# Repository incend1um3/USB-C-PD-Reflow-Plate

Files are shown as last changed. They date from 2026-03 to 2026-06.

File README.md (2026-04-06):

<h1 align="center">
	USB-C PD Reflow Plate
	<br />
	<br />
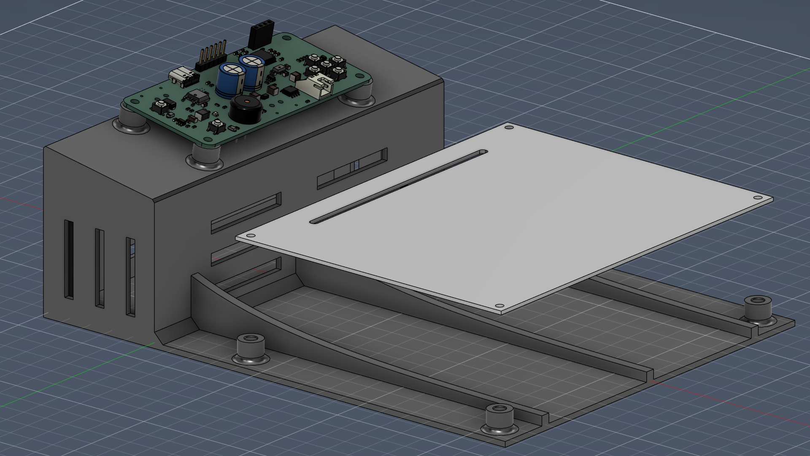
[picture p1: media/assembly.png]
Assembly
	
	<br />
</h1>

<h4 align="center">
A DIY PCB Reflow Plate. Accepts 300W from a DC power source, or 110W from USB PD.
</h4>

<div align="center">





</div>

<p align="center">
  <a href="#key-features">Key Features</a> •
  <a href="#hardware">Hardware</a> •
  <a href="#building-and-flashing-the-firmware">Building and Flashing</a> •
  <a href="#license">License</a>
</p>

## Key Features

- **Split design** that allows you to manufacture the heater PCB using aluminum
- Accepts **USB-C PD (up to 110W)** or **DC supply (up to 300W)**
- **STM32G431KBT6 microcontroller** with support for flashing over USB and SWD
- **1.3" OLED display** for selecting alloys and showing progress
- **40 KHz PWM power delivery** to the heating element + a **970μF capacitor bank** to keep the average current under power supply limits

## Motivation

I started this project because existing designs had some flaws I disliked such as:

- No USB-C PD support
- Using obsolete Atmega chips that are too expensive for what they offer
- Not being powerful enough or requiring AC voltages which I don't want to mess around with
- Putting the electronics and heating elements on the same FR-4 PCB, making the longevity of the board questionable

This project is intended to address all these issues.

## Hardware

The hardware is split into two separate PCBs - a controller board and the heating element. This allows you to manufacture the heating element using aluminium to increase its longevity.

### Controller Board

#### Schematic

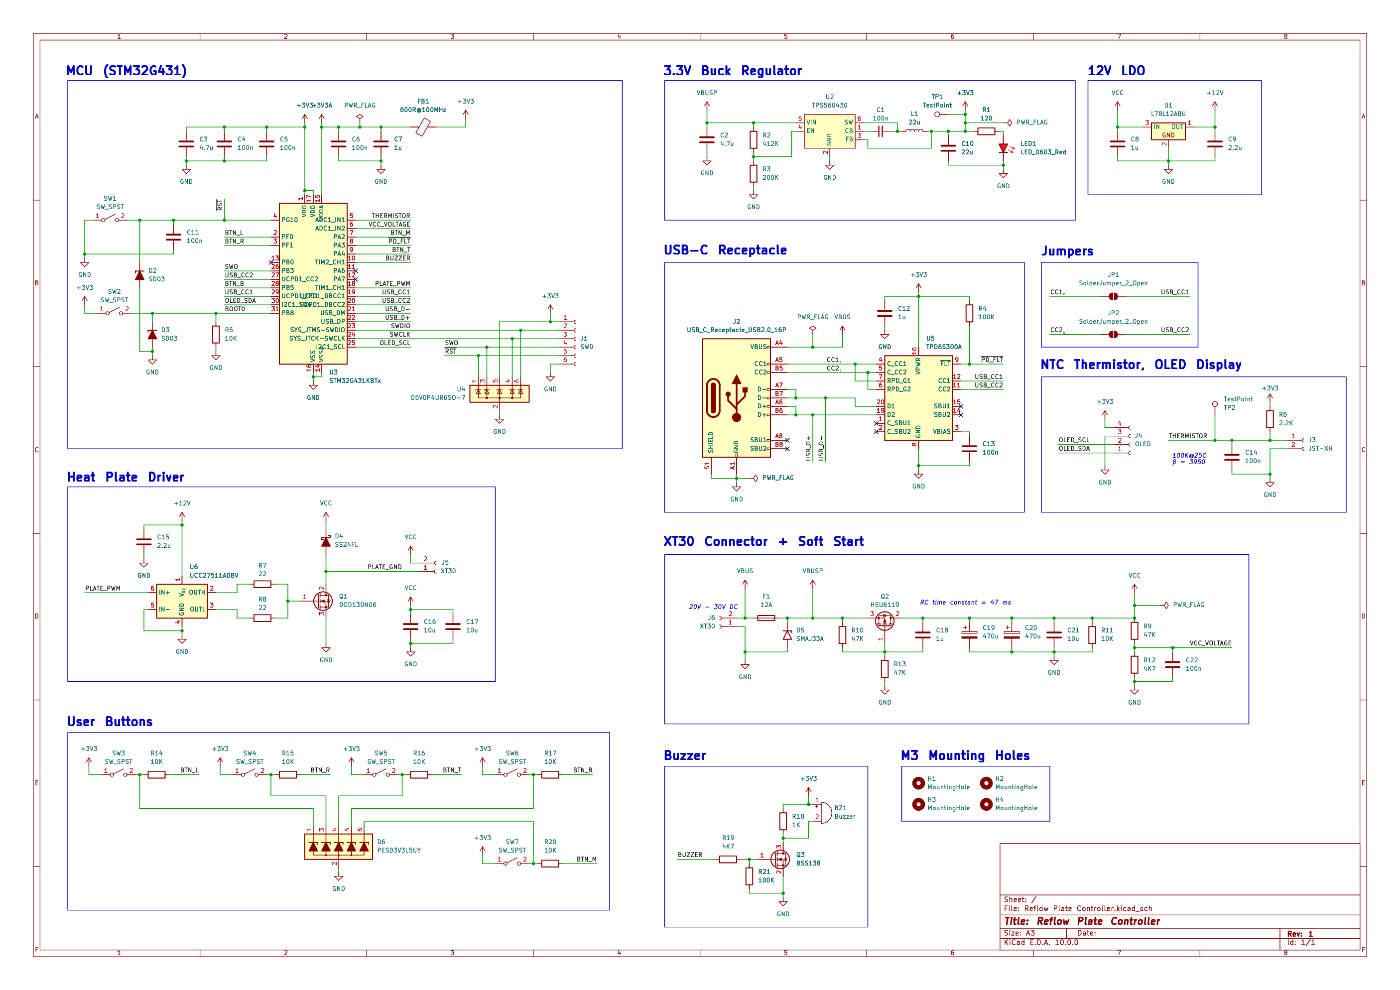
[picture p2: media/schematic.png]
Schematic


#### PCB

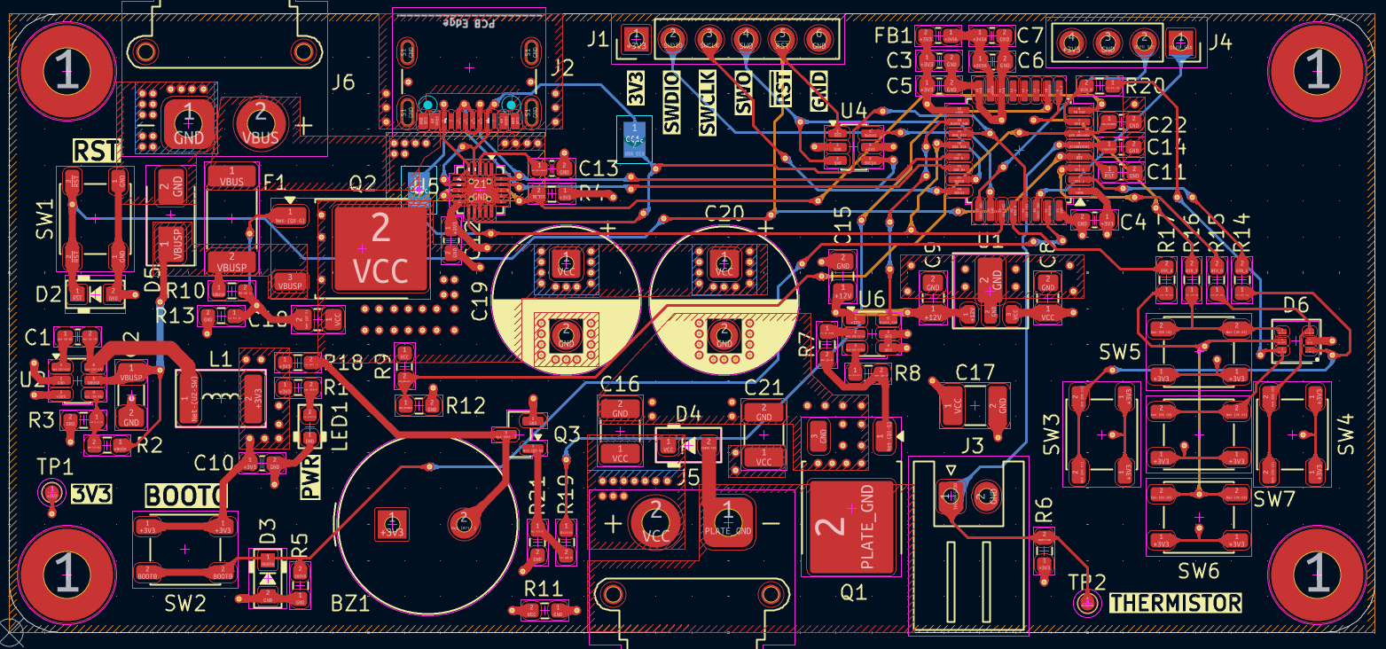
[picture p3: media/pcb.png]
PCB


The controller PCB uses a 4 layer SIGNAL-GND-PWR-SIGNAL stackup. It measures under 100x50 mm, so you can get it manufactured for cheap at JLCPCB. 2x 470μF aluminum polymer capacitors are used to keep the average current within limits and smooth out the power supply.

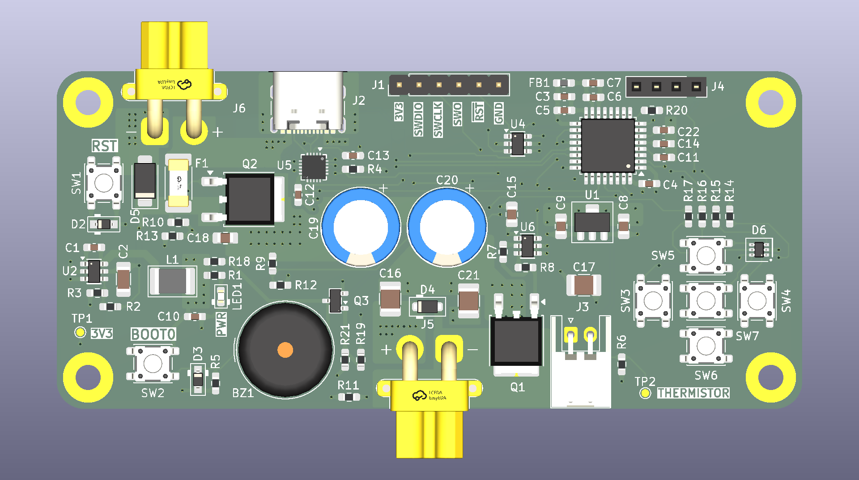
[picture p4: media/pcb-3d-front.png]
PCB 3D Render


### Heating Element

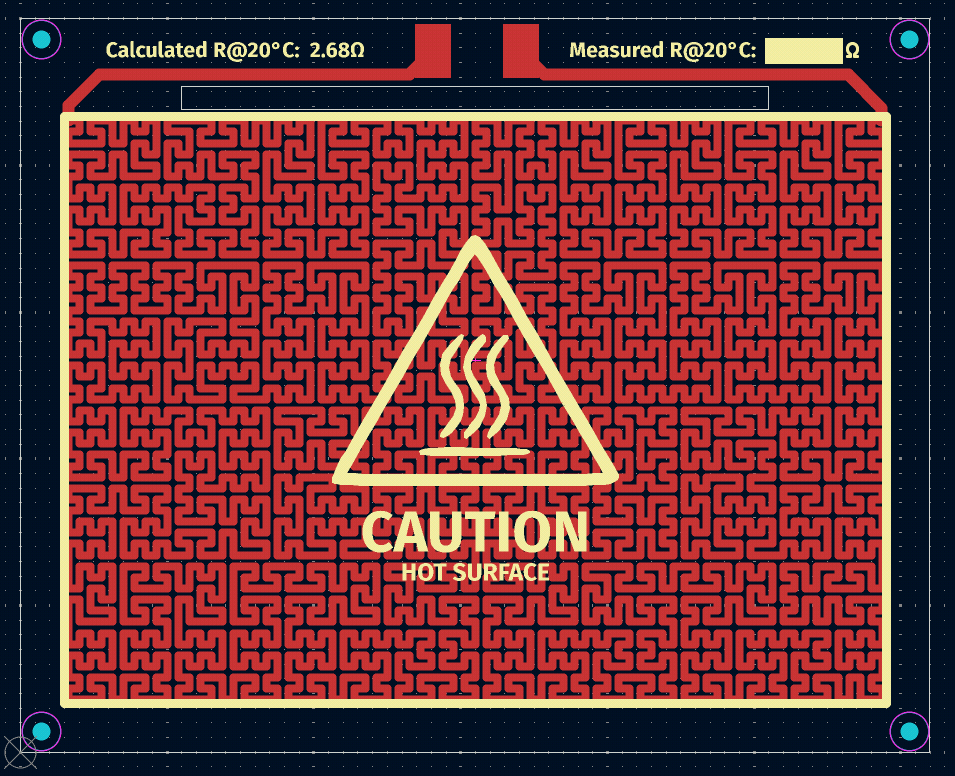
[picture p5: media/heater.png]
Heating Element


The traces are generated using the [Heater Generator Plugin](https://github.com/steltze/KiCad-Heater-Generator-Plugin), which uses the Hilbert Space Filling Curve to generate traces in a given bounding box.

The calculated resistance at 20°C is approximately 2.68Ω. The actual resistance after manufacturing can vary, but slight differences should not be a problem as long as the firmware is updated with the new value.

## Chassis

The chassis is made in Fusion360 and is designed to be printed using SLS/MJF nylon at JLC3DP. It occupies a bounding box of 220x166x73 mm and a total volume of 179 cm³.

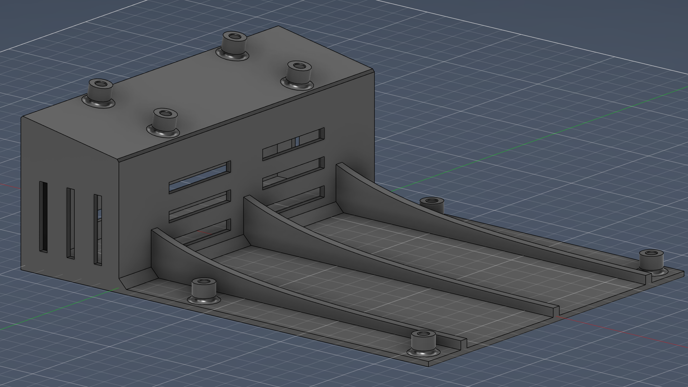
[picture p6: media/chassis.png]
Chassis


## Manufacturing

All files related to manufacturing can be found in the `production` folder.

### BOM

<details>
<summary>Click to Expand / Collapse</summary>
<br />

The list of PCB components can be found [here.](production/Reflow%20Plate%20Controller/BOM-Reflow%20Plate%20Controller.csv)

| Name | Comment | Price ($USD) | Link |
|---|---|---|---|
| PCB Components | | $25.63 | production/Reflow Plate Controller/BOM-Reflow Plate Controller.csv |
| 1.3" SSD1315 OLED Display | | $2.43 | <https://www.aliexpress.com/item/1005008365029314.html> |
| Glass NTC Thermistor | Must be able to withstand at least 250C | $4.03 | <https://www.aliexpress.com/item/1005008996648273.html> |
| Kapton Tape | For attaching the thermistor to the heating element | $2.72 | <https://www.aliexpress.com/item/33036160119.html> |
| XT30 Female Connector | For connecting the controller to the heating element | $2.17 | <https://www.aliexpress.com/item/1005011848365155.html> |
| M3x12 PEEK Screws | PEEK material chosen for insulation | $4.90 | <https://www.aliexpress.com/item/1005009212510720.html> |
| M3 Ceramic Washers | For insulation | $10.07 | <https://www.aliexpress.com/item/1005006898159426.html> |
| M3x45 Stainless Steel Standoffs | For insulation and attaching the heating element to the chassis | $2.55 | <https://www.aliexpress.com/item/1005010143571846.html> |
| M3x8 Screws | For attaching the controller PCB to the chassis | $1.61 | <https://www.aliexpress.com/item/1005010666684312.html> |
| M3x5x5 Heat Set Inserts | | $1.28 | <https://www.aliexpress.com/item/1005010449185019.html> |
| JLCPCB (Controller Board) | | $7.00 | |
| JLCPCBA (Controller Board) | | $14.53 | |
| JLCPCB (Heating Element) | | $12.40 | |
| JLC3DP (SLS 1172Pro Nylon) | | $59.95 | |
| JLCPCB Shipping | | $16.17 | |
| JLC3DP Shipping | | $17.07 | |
| LCSC Shipping | | $14.80 | |
| **Total** | | **$200.00** | |

</details>

### JLC Cart

<details>
<summary>Click to Expand / Collapse</summary>
<br />

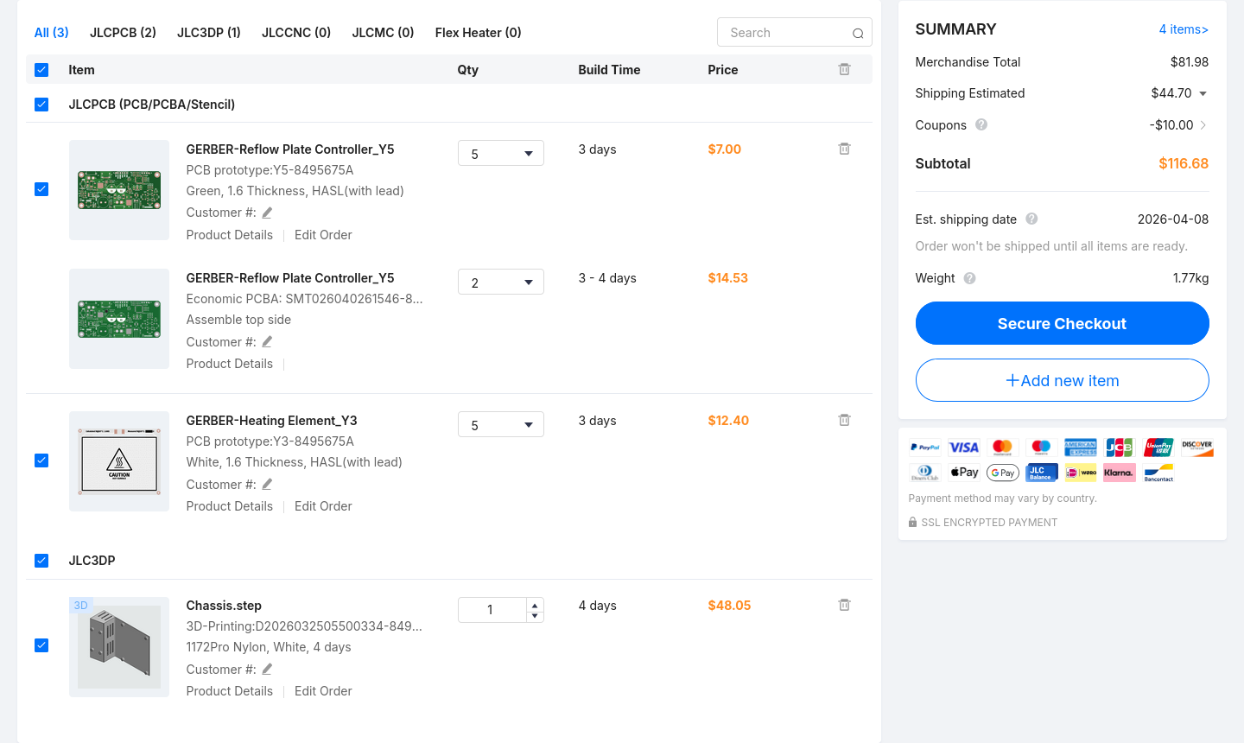
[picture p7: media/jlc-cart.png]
JLC Cart


</details>

### Aliexpress Cart

<details>
<summary>Click to Expand / Collapse</summary>
<br />

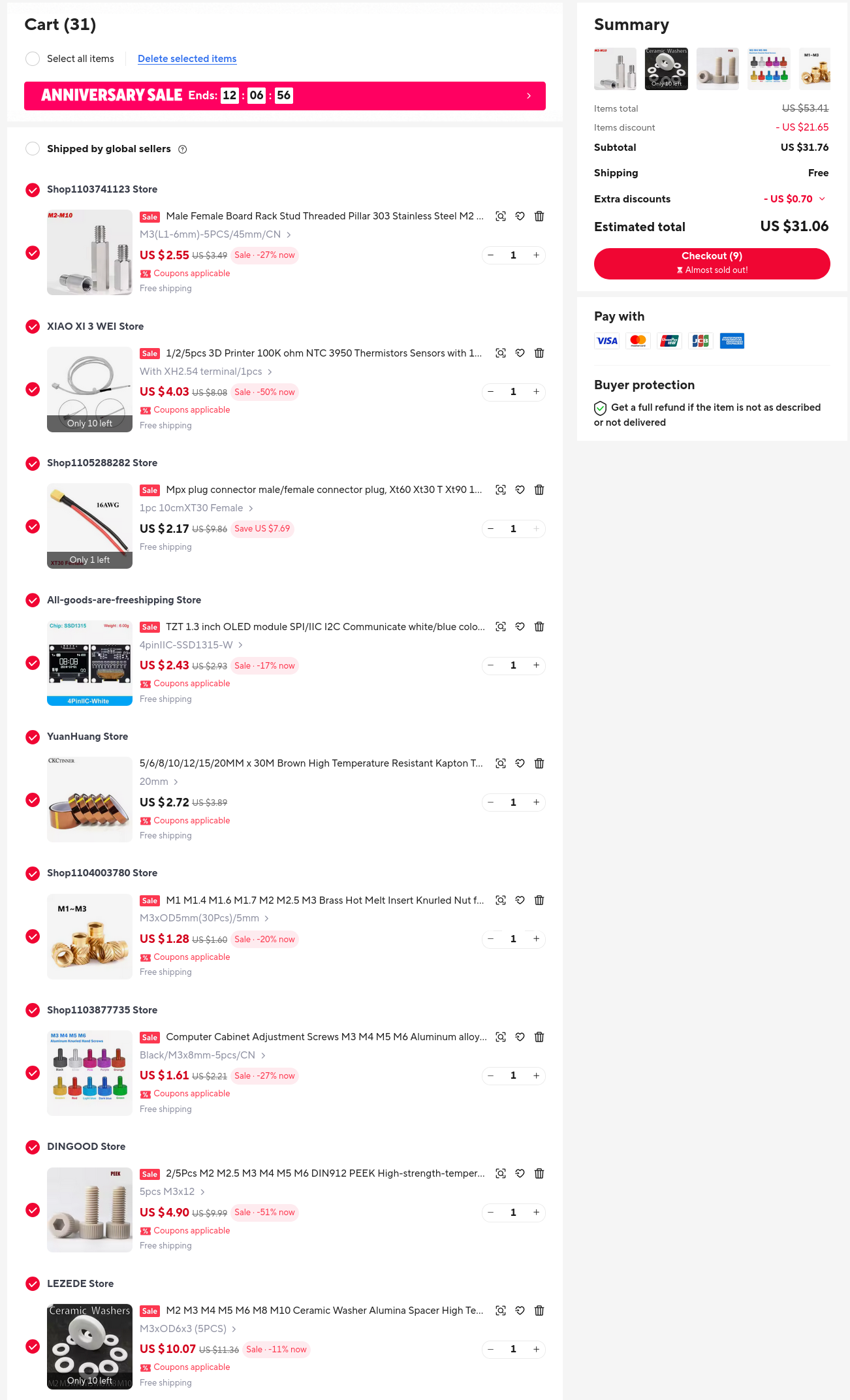
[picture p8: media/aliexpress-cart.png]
Aliexpress Cart


</details>

## Assembly

Heat up your soldering iron to the appropriate temperature for your chassis material. Take a heat-set insert, place it on a hole, and slowly push it through using the iron until the tip of the insert is flat with the surrounding surface. Repeat for the remaining screw holes.

Now you can go ahead and attach the PCBs using standoffs and screws.

## Building and Flashing the Firmware

The firmware is written in Rust. To build it, install the [rust toolchain](https://rust-lang.org/tools/install/) then run the following commands to install all the required components.

```bash
rustup target add thumbv7em-none-eabihf
cargo install cargo-binstall
cargo binstall cargo-dfu probe-rs-tools
```

### Flash Over USB

Plug in the controller board to your computer while holding the BOOT0 button to put the microcontroller in DFU mode. Then run:

```bash
cargo dfu --release
```

### Flash Over SWD (ST-LINK)

Connect your ST-LINK to the controller board using the SWD headers, then run:

```bash
cargo flash --release --chip STM32G431KB
```

## License

- `firmware/` is licensed under [GNU GPL v3](firmware/LICENSE)
- Rest of the repository is licensed under [CERN-OHL-S](LICENSE)

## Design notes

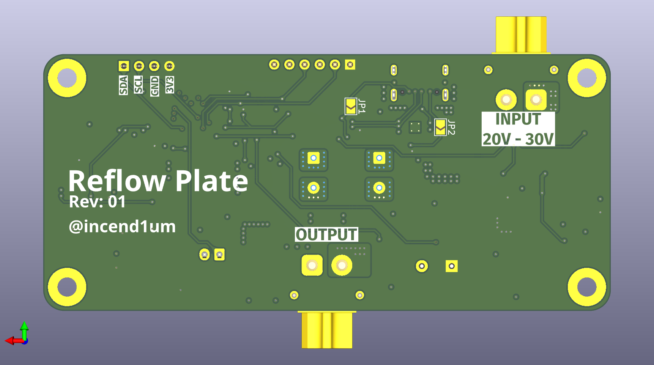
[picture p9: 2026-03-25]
media/pcb-3d-back.png

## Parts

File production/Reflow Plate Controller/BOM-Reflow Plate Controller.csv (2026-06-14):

Comment | Designator | Footprint | LCSC | Quantity
100K | R21,R4 | R_0603_1608Metric_Pad0.98x0.95mm_HandSolder | C14675 | 2
100n | C1,C11,C13,C14,C22,C4,C5,C6 | C_0603_1608Metric_Pad1.08x0.95mm_HandSolder | C1591 | 8
10K | R11,R14,R15,R16,R17,R20,R5 | R_0603_1608Metric_Pad0.98x0.95mm_HandSolder | C98220 | 7
10u | C16,C17,C21 | C_1210_3225Metric_Pad1.33x2.70mm_HandSolder | C77102 | 3
120 | R1 | R_0603_1608Metric_Pad0.98x0.95mm_HandSolder | C22787 | 1
12A | F1 | Fuse_2512_6332Metric_Pad1.52x3.35mm_HandSolder | C3014111 | 1
1K | R18 | R_0603_1608Metric_Pad0.98x0.95mm_HandSolder | C21190 | 1
1u | C18 | C_0805_2012Metric_Pad1.18x1.45mm_HandSolder | C15849 | 1
1u | C12,C7 | C_0603_1608Metric_Pad1.08x0.95mm_HandSolder | C1592 | 2
1u | C8 | C_0805_2012Metric_Pad1.18x1.45mm_HandSolder | C28323 | 1
2.2K | R6 | R_0603_1608Metric_Pad0.98x0.95mm_HandSolder | C4190 | 1
2.2u | C15,C9 | C_0805_2012Metric_Pad1.18x1.45mm_HandSolder | C377773 | 2
200K | R3 | R_0603_1608Metric_Pad0.98x0.95mm_HandSolder | C25811 | 1
22 | R7,R8 | R_0603_1608Metric_Pad0.98x0.95mm_HandSolder | C23345 | 2
22u | L1 | L_1812_4532Metric_Pad1.30x3.40mm_HandSolder | C5788457 | 1
22u | C10 | C_0603_1608Metric_Pad1.08x0.95mm_HandSolder | C59461 | 1
4.7u | C3 | C_0603_1608Metric_Pad1.08x0.95mm_HandSolder | C1705 | 1
4.7u | C2 | C_1206_3216Metric_Pad1.33x1.80mm_HandSolder | C51205 | 1
412K | R2 | R_0603_1608Metric_Pad0.98x0.95mm_HandSolder | C2933219 | 1
470u | C19,C20 | CP_Radial_D10.0mm_P5.00mm | C51953324 | 2
47K | R10,R13,R9 | R_0603_1608Metric_Pad0.98x0.95mm_HandSolder | C25819 | 3
4K7 | R12,R19 | R_0603_1608Metric_Pad0.98x0.95mm_HandSolder | C23162 | 2
600R@100MHz | FB1 | L_0603_1608Metric_Pad1.05x0.95mm_HandSolder | C85833 | 1
BSS138 | Q3 | SOT-23 | C40912 | 1
Buzzer | BZ1 | Buzzer_TDK_PS1240P02BT_D12.2mm_H6.5mm | C76873 | 1
D5V0P4UR6SO-7 | U4 | SOT-23-6 | C531179 | 1
HSU6119 | Q2 | TO-252-2 | C53244079 | 1
JST-XH | J3 | JST_XH_S2B-XH-A_1x02_P2.50mm_Horizontal | C163035 | 1
L78L12ABU | U1 | SOT-89-3 | C915681 | 1
LED_0603_Red | LED1 | LED_0603_1608Metric | C965799 | 1
PESD3V3L5UY | D6 | SOT-363_SC-70-6 | C477992 | 1
SD03 | D2,D3 | D_SOD-323_HandSoldering | C5369353 | 2
SMAJ33A | D5 | D_SMA | C134981 | 1
SS24FL | D4 | D_SOD-123F | C894433 | 1
STM32G431KBTx | U3 | LQFP-32_7x7mm_P0.8mm | C529357 | 1
SW_SPST | SW1,SW2,SW3,SW4,SW5,SW6,SW7 | SW_SPST_PTS647_Sx38 | C963225 | 7
TPD6S300A | U5 | WQFN-20-1EP_3x3mm_P0.4mm_EP1.7x1.7mm_ThermalVias | C2876380 | 1
TPS560430 | U2 | SOT-23-6 | C2071721 | 1
UCC27511ADBV | U6 | SOT-23-6 | C2676982 | 1
USB_C_Receptacle_USB2.0_16P | J2 | USB_C_Receptacle_GCT_USB4105-xx-A_16P_TopMnt_Horizontal | C165948 | 1
XT30 | J5,J6 | AMASS_XT30PW-F_1x02_P2.50mm_Horizontal | C2913282 | 2
DOD130N06 | Q1 | TO-252-2 |  | 1

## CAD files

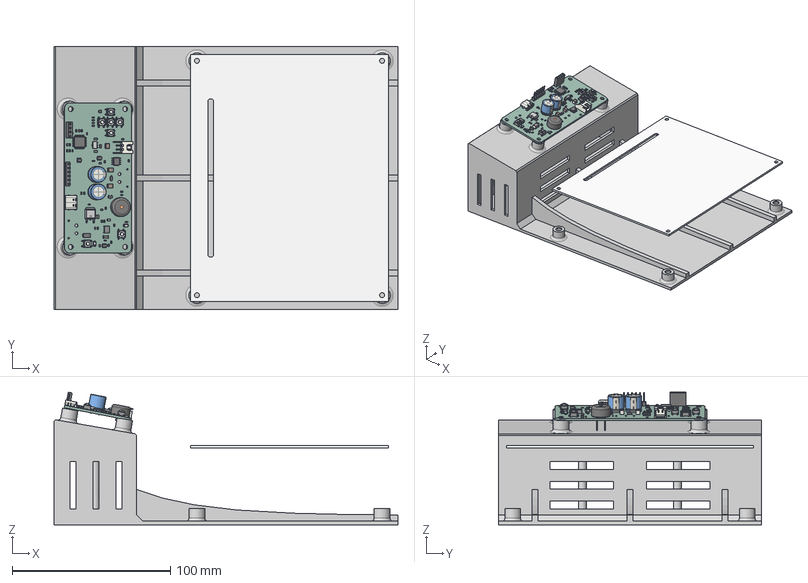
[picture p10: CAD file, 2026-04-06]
CAD/Assembly.step
217.2 x 166.0 x 83.8 mm
R_0603_1608Metric x 21
SOT-363_SC-70-6
L_1812_4532Metric
C_0603_1608Metric x 14
SOT-23-6 x 3
C_0805_2012Metric x 4
C_1210_3225Metric x 3
LQFP-32_7x7mm_P0.8mm
L_0603_1608Metric
Reflow Plate 1.17.1
SW_SPST_PTS647Sx38 x 7
PinHeader_1x06_P2.54mm_Vertical
Buzzer_TDK_PS1240P02BT_D12.2mm_H6.5mm
PinSocket_1x04_P2.54mm_Vertical
D_SOD-123F
Reflow Plate 1.44.1 x 2
CP_Radial_D10.0mm_P5.00mm x 2
Reflow Plate 1.50.1
LED_0805_2012Metric
USB_C_Receptacle_GCT_USB4105-xx-A_16P_TopMnt_Horizontal
C_1206_3216Metric
SOT-23
JST_XH_S2B-XH-A_1x02_P2.50mm_Horizontal
SOIC-8_3.9x4.9mm_P1.27mm
D_SMA
Reflow Plate_PCB
Heating Element_PCB
Chassis
DIN 653 - M1 x 2 Steel 4.6 Plain

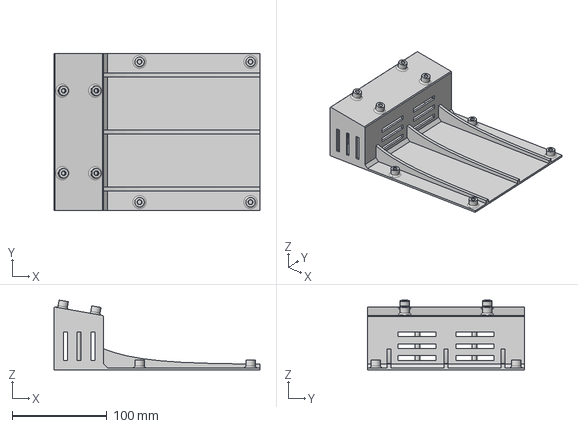
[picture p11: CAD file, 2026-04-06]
CAD/Chassis.step
217.2 x 166.0 x 73.7 mm

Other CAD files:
CAD/Assembly.f3z
CAD/Chassis.f3d

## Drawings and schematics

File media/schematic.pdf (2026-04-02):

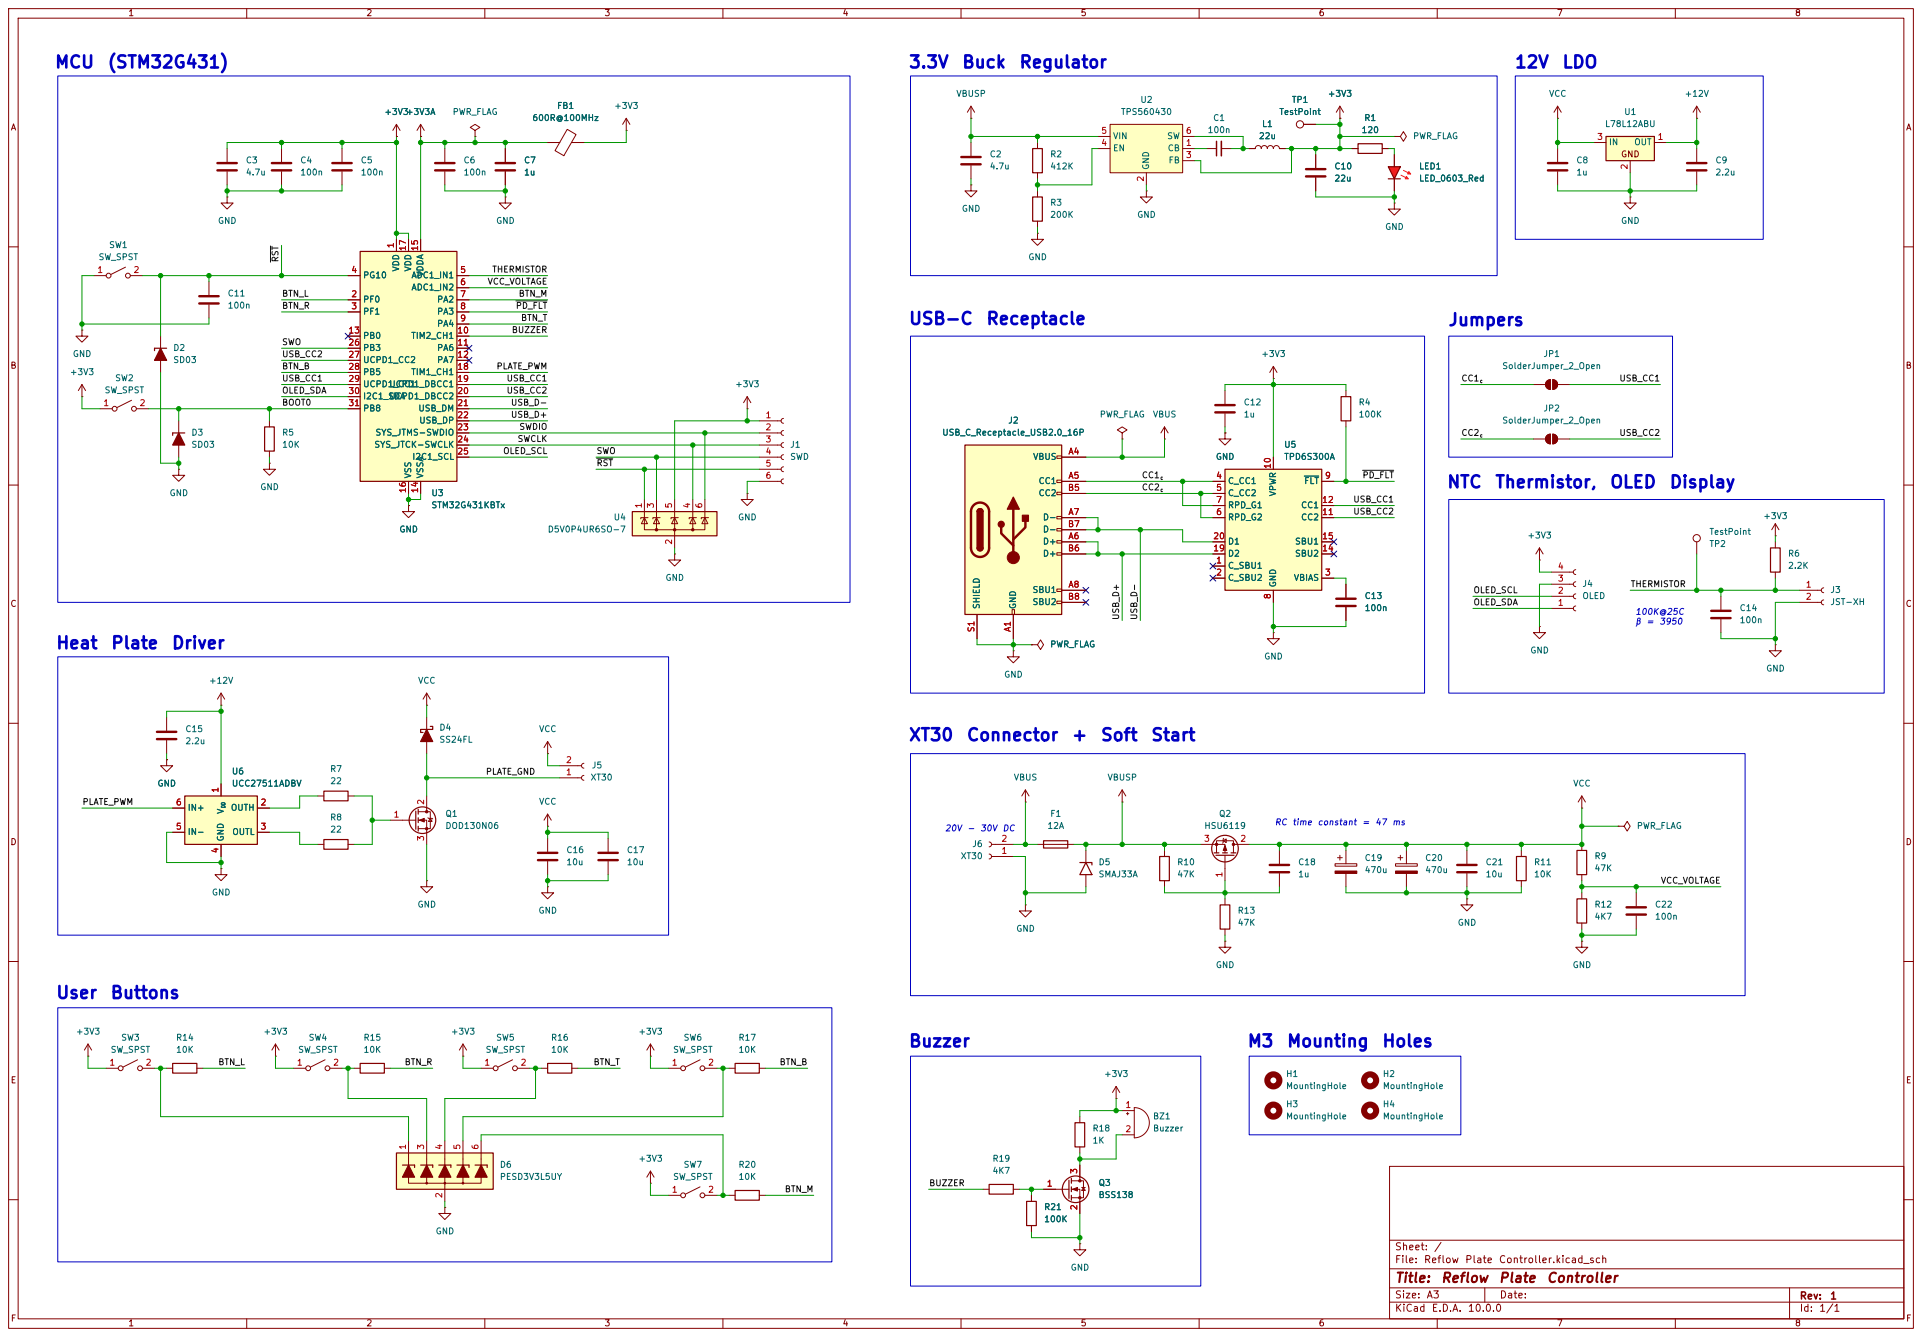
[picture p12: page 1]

NTC Thermistor, OLED Display

V DD 1 OUTH 2 OUTL 3 GND

Sheet: /
File: Reflow Plate Controller.kicad_sch
Title: Reflow Plate Controller

Size: A3 | Rev: 1 | F Date:
KiCad E.D.A. 10.0.0 | Id: 1/1

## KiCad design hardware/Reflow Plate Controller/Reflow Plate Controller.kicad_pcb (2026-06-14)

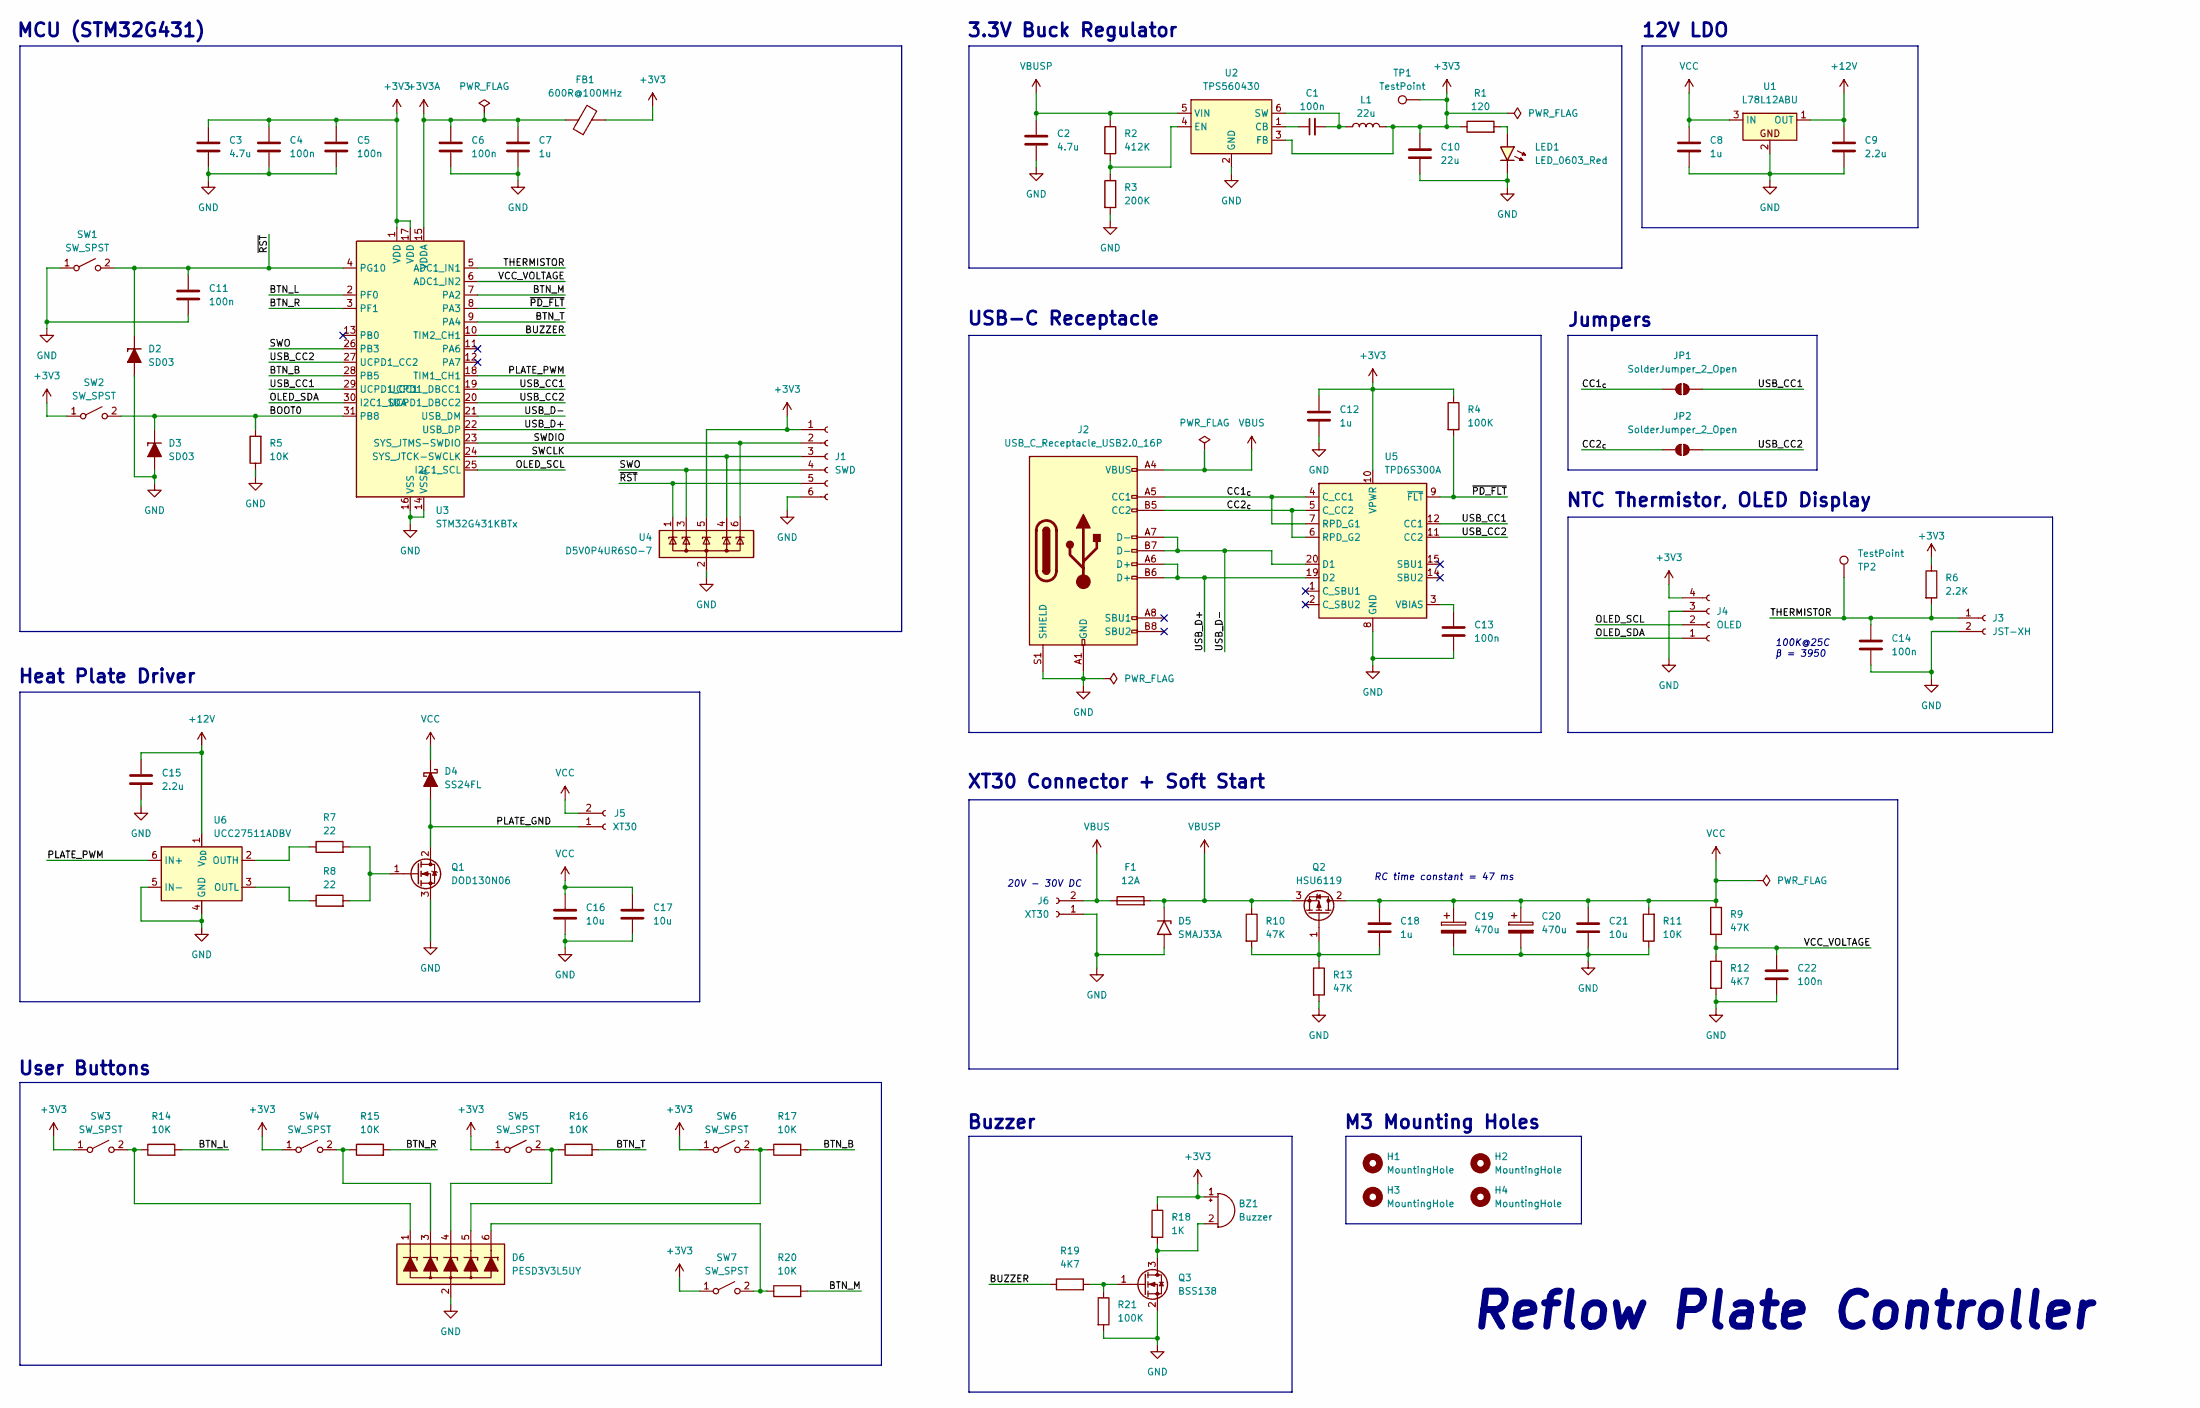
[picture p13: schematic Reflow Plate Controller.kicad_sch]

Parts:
BZ1: Buzzer; Buzzer_TDK_PS1240P02BT_D12.2mm_H6.5mm
C1, C4, C5, C6, C11, C13, C14, C22: 100n; C_0603_1608Metric_Pad1.08x0.95mm_HandSolder
C2: 4.7u; C_1206_3216Metric_Pad1.33x1.80mm_HandSolder
C3: 4.7u; C_0603_1608Metric_Pad1.08x0.95mm_HandSolder
C7, C12: 1u; C_0603_1608Metric_Pad1.08x0.95mm_HandSolder
C8, C18: 1u; C_0805_2012Metric_Pad1.18x1.45mm_HandSolder
C9, C15: 2.2u; C_0805_2012Metric_Pad1.18x1.45mm_HandSolder
C10: 22u; C_0603_1608Metric_Pad1.08x0.95mm_HandSolder
C16, C17, C21: 10u; C_1210_3225Metric_Pad1.33x2.70mm_HandSolder
C19, C20: 470u; CP_Radial_D10.0mm_P5.00mm
D2, D3: SD03; D_SOD-323_HandSoldering
D4: SS24FL; D_SOD-123F
D5: SMAJ33A; D_SMA
D6: PESD3V3L5UY; SOT-363_SC-70-6
F1: 12A; Fuse_2512_6332Metric_Pad1.52x3.35mm_HandSolder
FB1: 600R@100MHz; L_0603_1608Metric_Pad1.05x0.95mm_HandSolder
H1, H2, H3, H4: MountingHole; MountingHole_3.2mm_M3_Pad
J1: SWD; PinHeader_1x06_P2.54mm_Vertical
J2: USB_C_Receptacle_USB2.0_16P; USB_C_Receptacle_GCT_USB4105-xx-A_16P_TopMnt_Horizontal
J3: JST-XH; JST_XH_S2B-XH-A_1x02_P2.50mm_Horizontal
J4: OLED; PinSocket_1x04_P2.54mm_Vertical
J5, J6: XT30; AMASS_XT30PW-F_1x02_P2.50mm_Horizontal
JP1, JP2: SolderJumper_2_Open; SolderJumper-2_P1.3mm_Open_TrianglePad1.0x1.5mm
L1: 22u; L_1812_4532Metric_Pad1.30x3.40mm_HandSolder
LED1: LED_0603_Red; LED_0603_1608Metric
Q1: DOD130N06; TO-252-2
Q2: HSU6119; TO-252-2
Q3: BSS138; SOT-23
R1: 120; R_0603_1608Metric_Pad0.98x0.95mm_HandSolder
R2: 412K; R_0603_1608Metric_Pad0.98x0.95mm_HandSolder
R3: 200K; R_0603_1608Metric_Pad0.98x0.95mm_HandSolder
R4, R21: 100K; R_0603_1608Metric_Pad0.98x0.95mm_HandSolder
R5, R11, R14, R15, R16, R17, R20: 10K; R_0603_1608Metric_Pad0.98x0.95mm_HandSolder
R6: 2.2K; R_0603_1608Metric_Pad0.98x0.95mm_HandSolder
R7, R8: 22; R_0603_1608Metric_Pad0.98x0.95mm_HandSolder
R9, R10, R13: 47K; R_0603_1608Metric_Pad0.98x0.95mm_HandSolder
R12, R19: 4K7; R_0603_1608Metric_Pad0.98x0.95mm_HandSolder
R18: 1K; R_0603_1608Metric_Pad0.98x0.95mm_HandSolder
SW1, SW2, SW3, SW4, SW5, SW6, SW7: SW_SPST; SW_SPST_PTS647_Sx38
TP1, TP2: TestPoint; TestPoint_Pad_D1.0mm
U1: L78L12ABU; SOT-89-3
U2: TPS560430; SOT-23-6
U3: STM32G431KBTx; LQFP-32_7x7mm_P0.8mm
U4: D5V0P4UR6SO-7; SOT-23-6
U5: TPD6S300A; WQFN-20-1EP_3x3mm_P0.4mm_EP1.7x1.7mm_ThermalVias
U6: UCC27511ADBV; SOT-23-6

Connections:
+3V3: BZ1.1 (+), C3.1, C4.1, C5.1, C10.1, C12.1, FB1.2, J1.1, J4.4, L1.2, R1.1, R4.1, R6.1, R18.1, SW2.1 (A), SW3.1 (A), SW4.1 (A), SW5.1 (A), SW6.1 (A), SW7.1 (A), TP1.1 (1_1), U2.3 (FB), U3.1 (VDD), U3.17 (VDD), U4.5, U5.10 (VPWR)
+3V3A: C6.1, C7.1, FB1.1, U3.15 (VDDA)
+12V: C9.1, C15.1, U1.1 (OUT), U6.1 (V_{DD})
/BOOT0: D3.1, R5.2, SW2.2 (B), U3.31 (PB8)
/BTN_B: R17.2, U3.28 (PB5)
/BTN_L: R14.2, U3.2 (PF0)
/BTN_M: R20.2, U3.7 (PA2)
/BTN_R: R15.2, U3.3 (PF1)
/BTN_T: R16.2, U3.9 (PA4)
/BUZZER: R19.1, U3.10 (TIM2_CH1)
/CC1_{c}: J2.A5 (CC1), JP1.1 (A), U5.4 (C_CC1), U5.7 (RPD_G1)
/CC2_{c}: J2.B5 (CC2), JP2.1 (A), U5.5 (C_CC2), U5.6 (RPD_G2)
/OLED_SCL: J4.2, U3.25 (I2C1_SCL)
/OLED_SDA: J4.1, U3.30 (I2C1_SDA)
/PLATE_GND: D4.2 (A), J5.1, Q1.2 (D)
/PLATE_PWM: U3.18 (TIM1_CH1), U6.6 (IN+)
/SWCLK: J1.3, U3.24 (SYS_JTCK-SWCLK), U4.4
/SWDIO: J1.2, U3.23 (SYS_JTMS-SWDIO), U4.6
/SWO: J1.4, U3.26 (PB3), U4.3
/THERMISTOR: C14.1, J3.1, R6.2, TP2.1 (1_1), U3.5 (ADC1_IN1)
/USB_CC1: JP1.2 (B), U3.19 (UCPD1_DBCC1), U3.29 (UCPD1_CC1), U5.12 (CC1)
/USB_CC2: JP2.2 (B), U3.20 (UCPD1_DBCC2), U3.27 (UCPD1_CC2), U5.11 (CC2)
/USB_D+: J2.A6 (D+), J2.B6 (D+), U3.22 (USB_DP), U5.19 (D2)
/USB_D-: J2.A7 (D-), J2.B7 (D-), U3.21 (USB_DM), U5.20 (D1)
/VCC_VOLTAGE: C22.1, R9.2, R12.1, U3.6 (ADC1_IN2)
/~PD_FLT: R4.2, U3.8 (PA3), U5.9 (~FLT)
/~RST: C11.1, D2.1, J1.5, SW1.2 (B), U3.4 (PG10), U4.1
GND: C2.2, C3.2, C4.2, C5.2, C6.2, C7.2, C8.2, C9.2, C10.2, C11.2, C12.2, C13.2, C14.2, C15.2, C16.2, C17.2, C19.2, C20.2, C21.2, C22.2, D2.2, D3.2, D5.2 (A2), D6.2 (VN), J1.6, J2.A1 (GND), J2.A12 (GND), J2.B1 (GND), J2.B12 (GND), J2.S1 (SHIELD), J3.2, J4.3, J6.1, LED1.1 (K), Q1.3 (S), Q3.2 (S), R3.2, R5.1, R11.1, R12.2, R13.2, R21.2, SW1.1 (A), U1.2, U2.2 (GND), U3.14 (VSSA), U3.16 (VSS), U3.32 (VSS), U4.2, U5.8 (GND), U5.13 (GND), U5.16 (GND), U5.17 (GND), U5.18 (GND), U5.21 (GND), U6.4 (GND), U6.5 (IN-)
unnamed: BZ1.2 (-), Q3.3 (D), R18.2
unnamed: D6.1 (L1), R14.1, SW3.2 (B)
unnamed: D6.3 (L2), R15.1, SW4.2 (B)
unnamed: D6.4 (L3), R16.1, SW5.2 (B)
unnamed: D6.5 (L4), R17.1, SW6.2 (B)
unnamed: D6.6 (L5), R20.1, SW7.2 (B)
unnamed: LED1.2 (A), R1.2
unnamed: Q1.1 (G), R7.2, R8.2
unnamed: C18.2, Q2.1 (G), R10.2, R13.1
unnamed: Q3.1 (G), R19.2, R21.1
unnamed: C1.1, U2.1 (CB)
unnamed: R2.2, R3.1, U2.4 (EN)
unnamed: C1.2, L1.1, U2.6 (SW)
unnamed: C13.1, U5.3 (VBIAS)
unnamed: R7.1, U6.2 (OUTH)
unnamed: R8.1, U6.3 (OUTL)
VBUS: F1.1, J2.A4 (VBUS), J2.A9 (VBUS), J2.B4 (VBUS), J2.B9 (VBUS), J6.2
VBUSP: C2.1, D5.1 (A1), F1.2, Q2.3 (S), R2.1, R10.1, U2.5 (VIN)
VCC: C8.1, C16.1, C17.1, C18.1, C19.1, C20.1, C21.1, D4.1 (K), J5.2, Q2.2 (D), R9.1, R11.2, U1.3 (IN)

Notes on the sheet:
Heat Plate Driver
Jumpers
3.3V Buck Regulator
Buzzer
RC time constant = 47 ms
User Buttons
M3 Mounting Holes
NTC Thermistor, OLED Display
USB-C Receptacle
Reflow Plate Controller
20V - 30V DC
XT30 Connector + Soft Start
MCU (STM32G431)
12V LDO
100K@25C β = 3950

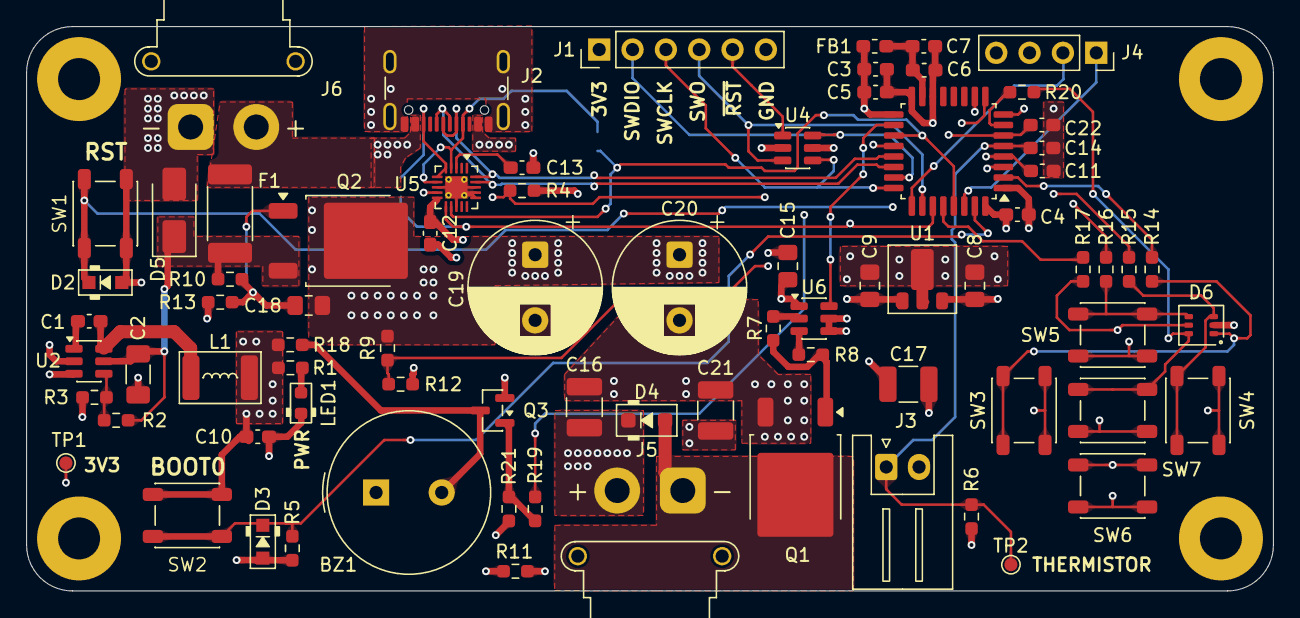
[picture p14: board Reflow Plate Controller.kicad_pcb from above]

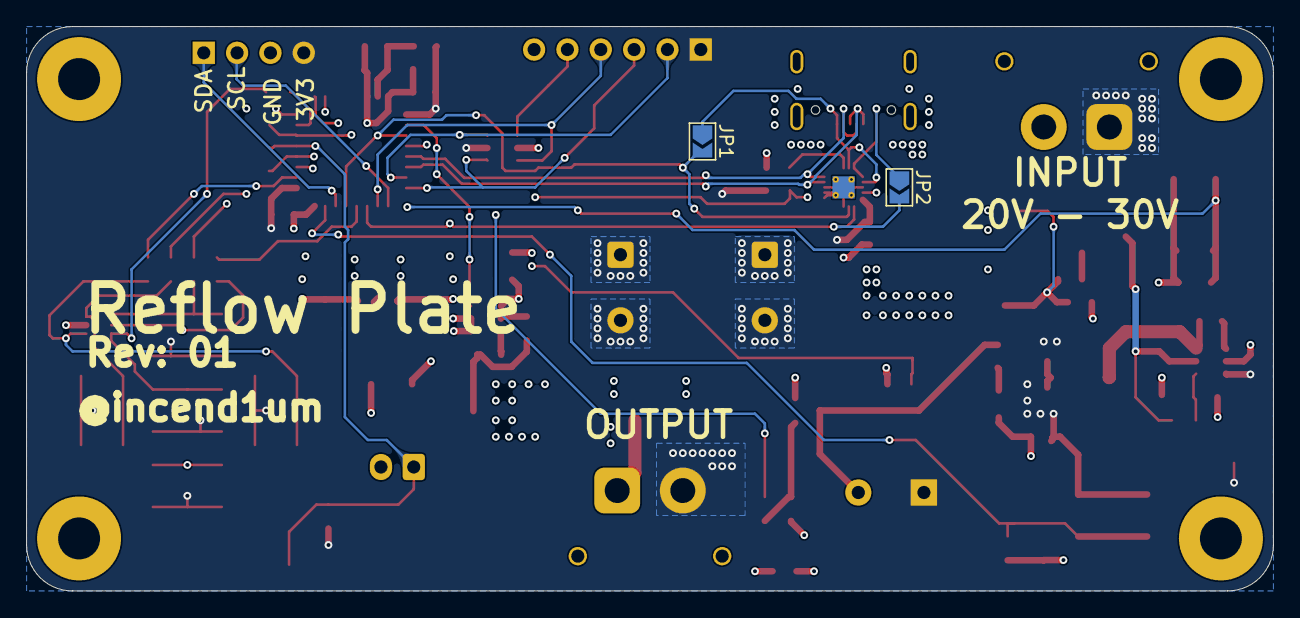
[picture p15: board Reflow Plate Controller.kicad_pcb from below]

Board: 4 copper layers, 95.0 x 43.0 mm, 83 parts (2 on the bottom side), 47 nets.

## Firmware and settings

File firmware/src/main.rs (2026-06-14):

#![no_std]
#![no_main]

extern crate uom;

use core::panic;

use crate::pd::ucpd_task;
use crate::profiles::AlloyReflowProfile;
use crate::ui::draw_cooling_screen;
use defmt::{debug, info};
use embassy_executor::Spawner;
use embassy_futures::select::{Either, select, select_array};
use embassy_stm32::adc::{AdcChannel, AdcConfig, AnyAdcChannel, Rovsm, SampleTime, Trovs};
use embassy_stm32::peripherals::{DMA1_CH1, DMA1_CH2, DMA1_CH4, DMA1_CH5, DMA2_CH1};
use embassy_stm32::time::Hertz;
use embassy_stm32::timer::simple_pwm::SimplePwmChannel;
use embassy_stm32::{Peri, dma, gpio};
use embassy_stm32::{
    adc::Adc,
    bind_interrupts,
    exti::{self, ExtiInput},
    gpio::{OutputType, Pull},
    i2c::{self, I2c},
    interrupt, peripherals,
    time::khz,
    timer::simple_pwm::{PwmPin, SimplePwm},
};
use embassy_time::{Duration, Instant, Ticker, Timer, WithTimeout};
use embedded_graphics::mono_font::MonoTextStyle;
use embedded_graphics::mono_font::ascii::FONT_8X13;
use embedded_graphics::pixelcolor::BinaryColor;
use embedded_graphics::prelude::*;
use embedded_graphics::primitives::Rectangle;
use embedded_graphics::text::Text;
use embedded_layout::align::{Align, horizontal, vertical};
use pid::Pid;
use ssd1315::Ssd1315;
use ssd1315::config::Ssd1315DisplayConfig;
use ssd1315::interface::I2cDisplayInterface;

use {defmt_rtt as _, panic_probe as _};

mod pd;
mod profiles;
mod ui;

const HEATER_RESISTANCE: f32 = 2.68;

bind_interrupts!(
    struct Irqs {
        I2C1_ER => i2c::ErrorInterruptHandler<peripherals::I2C1>;
        I2C1_EV => i2c::EventInterruptHandler<peripherals::I2C1>;
        I2C2_ER => i2c::ErrorInterruptHandler<peripherals::I2C2>;
        I2C2_EV => i2c::EventInterruptHandler<peripherals::I2C2>;
        EXTI0 => exti::InterruptHandler<interrupt::typelevel::EXTI0>;
        EXTI1 => exti::InterruptHandler<interrupt::typelevel::EXTI1>;
        EXTI2 => exti::InterruptHandler<interrupt::typelevel::EXTI2>;
        EXTI4 => exti::InterruptHandler<interrupt::typelevel::EXTI4>;
        EXTI9_5 => exti::InterruptHandler<interrupt::typelevel::EXTI9_5>;
        DMA1_CHANNEL1 => dma::InterruptHandler<DMA1_CH1>;
        DMA1_CHANNEL2 => dma::InterruptHandler<DMA1_CH2>;
        DMA1_CHANNEL4 => dma::InterruptHandler<DMA1_CH4>;
        DMA1_CHANNEL5 => dma::InterruptHandler<DMA1_CH5>;
        DMA2_CHANNEL1 => dma::InterruptHandler<DMA2_CH1>;
    }
);

#[embassy_executor::main]
async fn main(spawner: Spawner) {
    let mut config = embassy_stm32::Config::default();
    config.enable_ucpd1_dead_battery = true;
    use embassy_stm32::rcc::*;
    config.rcc.pll = Some(Pll {
        source: PllSource::HSI,
        prediv: PllPreDiv::DIV4,
        mul: PllMul::MUL85,
        divp: Some(PllPDiv::DIV12),
        divq: None,
        // Main system clock at 170 MHz
        divr: Some(PllRDiv::DIV2),
    });
    config.rcc.mux.adc12sel = mux::Adcsel::PLL1_P;
    config.rcc.sys = Sysclk::PLL1_R;
    config.rcc.mux.i2c1sel = mux::I2csel::SYS;
    let mut p = embassy_stm32::init(config);

    let pd_flt = gpio::Input::new(p.PA3, Pull::None);
    spawner.spawn(ucpd_task(p.UCPD1, p.PB6, p.PB4, p.DMA1_CH1, p.DMA1_CH2, pd_flt).unwrap());

    let buzzer_pin = PwmPin::new(p.PA5, OutputType::PushPull);
    let mut buzzer_pwm_driver = SimplePwm::new(
        p.TIM2,
        Some(buzzer_pin),
        None,
        None,
        None,
        khz(2),
        Default::default(),
    );
    let mut buzzer = buzzer_pwm_driver.ch1();
    buzzer.set_duty_cycle_percent(1);

    let plate_mosfet_pin = PwmPin::new(p.PA8, OutputType::PushPull);
    let mut plate_mosfet = SimplePwm::new(
        p.TIM1,
        Some(plate_mosfet_pin),
        None,
        None,
        None,
        khz(40),
        Default::default(),
    );
    let mut plate_mosfet = plate_mosfet.ch1();

    let mut adc_config = AdcConfig::default();
    // 0x02 = 8x oversampling
    // log2(8) = 3, 12 + 3 = 15 bits sampled
    adc_config.oversampling_ratio = Some(0x02);
    // 15 bits >> 1 = 14 bits returned
    // the extra samples act as a hardware mean filter
    adc_config.oversampling_shift = Some(1);
    adc_config.oversampling_mode = Some((Rovsm::RESUMED, Trovs::AUTOMATIC, true));

    let mut adc1 = Adc::new(p.ADC1, adc_config);
    let mut ntc_pin = p.PA0.degrade_adc();
    let mut vsys_pin = p.PA1.degrade_adc();

    let mut c = i2c::Config::default();
    c.frequency = Hertz::khz(200);
    let display_interface = I2cDisplayInterface::new_interface(I2c::new(
        p.I2C1, p.PA15, p.PB7, p.DMA1_CH4, p.DMA1_CH5, Irqs, c,
    ));

    info!("Initiating screen");
    let mut display = ssd1315::Ssd1315::new(display_interface);
    display.set_custom_config(Ssd1315DisplayConfig::preset_config());
    display.init_screen();

    let display_area = display.bounding_box();
    Text::new(
        "Negotiating\nUSB-C PD",
        Point::zero(),
        MonoTextStyle::new(&FONT_8X13, BinaryColor::On),
    )
    .align_to(&display_area, horizontal::Center, vertical::Center)
    .draw(&mut display)
    .unwrap();
    display.flush_screen();

    let mut pd_state_receiver = pd::STATE.receiver().unwrap();
    let pd_state = pd_state_receiver
        .changed()
        .with_timeout(Duration::from_secs(4))
        .await
        .unwrap_or(pd::State::NotAttached);

    match pd_state {
        pd::State::Good(_) => info!("USB PD negotiation complete"),
        pd::State::Error => {
            ui::draw_pd_error_screen(&mut display, &display_area);
            panic!("USB PD error");
        }
        _ => info!("USB PD negotation timed out. Assuming DC power."),
    }

    let alloy_names: heapless::Vec<&str, 4> = profiles::PROFILES.iter().map(|p| p.alloy).collect();

    let _btn_up = ExtiInput::new(p.PA4, p.EXTI4, Pull::Down, Irqs);
    let _btn_down = ExtiInput::new(p.PB5, p.EXTI5, Pull::Down, Irqs);
    let mut btn_left = ExtiInput::new(p.PF0, p.EXTI0, Pull::Down, Irqs);
    let mut btn_right = ExtiInput::new(p.PF1, p.EXTI1, Pull::Down, Irqs);
    let mut btn_middle = ExtiInput::new(p.PA2, p.EXTI2, Pull::Down, Irqs);

    let mut selected_index = 0;

    buzzer.enable();
    Timer::after_millis(500).await;
    buzzer.disable();

    loop {
        ui::draw_profiles(
            &mut display,
            &display_area,
            &alloy_names,
            selected_index,
            &pd_state,
            read_vcc_voltage(&mut adc1, &mut vsys_pin),
        );
        display.flush_screen();

        loop {
            match select_array([
                btn_left.wait_for_rising_edge(),
                btn_right.wait_for_rising_edge(),
                btn_middle.wait_for_rising_edge(),
            ])
            .await
            .1
            {
                // LEFT
                0 => {
                    selected_index =
                        (selected_index + profiles::PROFILES.len() - 1) % profiles::PROFILES.len();
                }
                // RIGHT
                1 => {
                    selected_index = (selected_index + 1) % profiles::PROFILES.len();
                }
                // MIDDLE
                2 => {
                    break;
                }
                _ => unreachable!(),
            }

            ui::draw_profiles(
                &mut display,
                &display_area,
                &alloy_names,
                selected_index,
                &pd_state,
                read_vcc_voltage(&mut adc1, &mut vsys_pin),
            );
            display.flush_screen();
        }

        let buttons_fut = btn_middle.wait_for_rising_edge();

        info!(
            "Starting reflow with profile: {}",
            profiles::PROFILES[selected_index].alloy
        );
        let reflow_fut = reflow(
            profiles::PROFILES[selected_index],
            &pd_state,
            &mut adc1,
            &mut ntc_pin,
            &mut vsys_pin,
            p.DMA2_CH1.reborrow(),
            &mut plate_mosfet,
            &mut display,
            display_area,
        );

        match select(reflow_fut, buttons_fut).await {
            Either::First(res) => {
                if res.is_err() {
                    for _ in 0..4 {
                        buzzer.enable();
                        Timer::after_millis(200).await;
                        buzzer.disable();
                        Timer::after_millis(100).await;
                    }
                } else {
                    buzzer.enable();
                    Timer::after_millis(500).await;
                    buzzer.disable();
                }
            }
            Either::Second(_) => {
                info!("Reflow cancelled by user");
                plate_mosfet.disable();
                buzzer.enable();
                Timer::after_millis(300).await;
                buzzer.disable();
            }
        };
    }
}

const R_PULLUP: f32 = 2200.0; // 2.2K
const R_NOMINAL: f32 = 100_000.0; // 100K @ 25°C
const B: f32 = 3950.0;
const T_NOMINAL: f32 = 298.15; // 25°C in Kelvin

fn adc_to_celsius(adc_raw: u16, adc_max: u16) -> f32 {
    let v_ratio = adc_raw as f32 / adc_max as f32;

    // NTC is on the low side, so:
    let r_ntc = R_PULLUP * v_ratio / (1.0 - v_ratio);

    let temp_k = 1.0 / (1.0 / T_NOMINAL + (1.0 / B) * libm::logf(r_ntc / R_NOMINAL));
    temp_k - 273.15
}

fn adc_to_voltage(adc_raw: u16, adc_max: u16) -> f32 {
    const VREF: f32 = 3.3;
    VREF * adc_raw as f32 / adc_max as f32
}

fn read_vcc_voltage(
    adc: &mut Adc<'static, peripherals::ADC1>,
    vsys_pin: &mut AnyAdcChannel<'_, peripherals::ADC1>,
) -> f32 {
    let reading = adc.blocking_read(vsys_pin, SampleTime::CYCLES640_5);
    let voltage = adc_to_voltage(reading, 2u16.pow(14) - 1);

    const R_UP: f32 = 47_000f32;
    const R_DOWN: f32 = 4_700f32;

    voltage * ((R_UP + R_DOWN) / R_DOWN)
}

/// Computes the resistance of copper at a given temperature using a quadratic
/// polynomial model (IEC 60028 / IACS standard for annealed copper).
///
/// # Arguments
/// * `r20`  - Resistance at 20°C (in any consistent unit, e.g. Ohms)
/// * `temp` - Target temperature in °C (accurate from 0°C to 260°C)
///
/// # Returns
/// Resistance at `temp` in the same units as `r20`.
///
/// # Model
/// Uses the second-order polynomial:
///   R(T) = R₂₀ × (1 + α·ΔT + β·ΔT²)
///   where ΔT = T − 20°C
///
/// Coefficients (IEC 60028, annealed copper, 100% IACS):
///   α₀ = 4.041e-3 /°C  (linear coefficient at 0°C)
///   β  = −6.0e-7  /°C² (quadratic coefficient)
///   α₂₀ is derived by re-referencing α₀ and β to T=20°C.
fn copper_resistance(r20: f32, temp: f32) -> f32 {
    // IEC 60028 coefficients referenced to 0°C
    const ALPHA_0: f32 = 4.041e-3; // /°C
    const BETA: f32 = -6.0e-7; // /°C²

    // Re-reference to 20°C so the caller can pass R at 20°C directly.
    // R(T)   = R₀ · (1 + α₀·T  + β·T²)
    // R(20)  = R₀ · (1 + α₀·20 + β·400)
    // R(T)/R(20) = (1 + α₀·T + β·T²) / (1 + α₀·20 + β·400)
    let denom = 1.0 + ALPHA_0 * 20.0 + BETA * 400.0;
    let numer = 1.0 + ALPHA_0 * temp + BETA * temp * temp;

    r20 * (numer / denom)
}

fn maximum_pwm_duty_cycle_percentage(
    voltage: f32,
    maximum_current: f32,
    r20: f32,
    temp: f32,
) -> f32 {
    let r_t = copper_resistance(r20, temp);
    ((maximum_current * r_t / voltage) * 100.0).clamp(0.0, 100.0)
}

async fn read_ntc(
    mut dma: Peri<'_, peripherals::DMA2_CH1>,
    adc: &mut Adc<'static, peripherals::ADC1>,
    ntc_pin: &mut AnyAdcChannel<'_, peripherals::ADC1>,
) -> f32 {
    // embassy bug; replace with a single adc.read later
    let mut readings = [0u16; 5];
    for r in readings.iter_mut() {
        let mut buf = [0u16];
        adc.read(
            dma.reborrow(),
            Irqs,
            [(&mut *ntc_pin, SampleTime::CYCLES247_5)].into_iter(),
            &mut buf,
        )
        .await;
        *r = buf[0];
    }
    readings.sort_unstable();
    adc_to_celsius(readings[2], 2u16.pow(14) - 1)
}

async fn reflow<I: display_interface::WriteOnlyDataCommand>(
    profile: &'static AlloyReflowProfile,
    pd_state: &pd::State,
    adc: &mut Adc<'static, peripherals::ADC1>,
    ntc_pin: &mut AnyAdcChannel<'_, peripherals::ADC1>,
    vsys_pin: &mut AnyAdcChannel<'_, peripherals::ADC1>,
    mut dma: Peri<'_, peripherals::DMA2_CH1>,
    plate_pwm: &mut SimplePwmChannel<'_, peripherals::TIM1>,
    display: &mut Ssd1315<I>,
    display_area: Rectangle,
) -> Result<(), ()> {
    plate_pwm.set_duty_cycle(0);
    plate_pwm.enable();

    // USB-C PD chargers typically have a maximum current limit of 5A.
    // If we're running on a plain DC supply, assume we're allowed a maximum of 10A.
    let maximum_current = match pd_state {
        pd::State::Good(limits) => limits.max_current,
        pd::State::NotAttached => 10.0,
        pd::State::Error => return Err(()),
    };

    let voltage = if let pd::State::Good(limits) = pd_state {
        limits.voltage
    } else {
        read_vcc_voltage(adc, vsys_pin)
    };

    let initial_temp = read_ntc(dma.reborrow(), adc, ntc_pin).await;

    let beginning = Instant::now();

    let mut pid: Pid<f32> = Pid::new(0.0, 100.0);
    pid.p(5.0, 100.0);
    pid.i(0.5, 100.0);
    pid.d(0.2, 50.0);

    let mut ticker = Ticker::every(Duration::from_hz(20));
    let mut display_refresh_counter = 0u8;
    let mut previous_temp = None;
    loop {
        let raw_temp = read_ntc(dma.reborrow(), adc, ntc_pin).await;
        // EMA Filter
        let temp = previous_temp
            .map(|t| 0.5 * raw_temp + 0.5 * t)
            .unwrap_or(raw_temp);
        previous_temp = Some(temp);

        debug!("Temperature: {}°C", temp as i16);

        if let Some(reflow_status) =
            profile.get_status(beginning.elapsed().as_secs() as u16, initial_temp)
        {
            debug!(
                "Time left in phase: {} seconds",
                reflow_status.time_left_in_phase
            );

            pid.output_limit = maximum_pwm_duty_cycle_percentage(
                voltage,
                maximum_current,
                HEATER_RESISTANCE,
                temp,
            );
            pid.setpoint(reflow_status.target_temp);

            let duty_cycle = libm::roundf(pid.next_control_output(temp).output.max(0.0)) as u8;
            plate_pwm.set_duty_cycle_percent(duty_cycle);

            if display_refresh_counter == 0 {
                ui::draw_progress(
                    display,
                    display_area,
                    beginning.elapsed(),
                    &reflow_status,
                    temp,
                    duty_cycle,
                    read_vcc_voltage(adc, vsys_pin),
                )
                .unwrap();
                display.flush_screen();
            }
            display_refresh_counter = (display_refresh_counter + 1) % 5;

            ticker.next().await;
        } else {
            info!("Completed all heating phases");
            break;
        }
    }

    plate_pwm.disable();
    info!("Starting cooling phase");

    let mut ticker = Ticker::every(Duration::from_hz(2));
    loop {
        let temp = read_ntc(dma.reborrow(), adc, ntc_pin).await;
        draw_cooling_screen(display, &display_area, temp).unwrap();
        display.flush_screen();

        if temp < 45.0 {
            info!("Cooling done");
            break;
        }

        ticker.next().await;
    }

    Ok(())
}

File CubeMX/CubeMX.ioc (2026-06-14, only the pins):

Mcu.UserName=STM32G431KBTx
PA0.Signal=ADC1_IN1
PA1.Signal=ADC1_IN2
PA10.Signal=UCPD1_DBCC2
PA11.Signal=USB_DM
PA12.Signal=USB_DP
PA13.Signal=SYS_JTMS-SWDIO
PA14.Signal=SYS_JTCK-SWCLK
PA15.Signal=I2C1_SCL
PA5.Signal=S_TIM2_CH1
PA6.Signal=ADC2_IN3
PA8.Signal=S_TIM1_CH1
PA9.Signal=UCPD1_DBCC1
PB3.Signal=SYS_JTDO-SWO
PB4.Signal=UCPD1_CC2
PB6.Signal=UCPD1_CC1
PB7.Signal=I2C1_SDA

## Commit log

2026-04-02 Fix a few layout and component selection issues
    - Replace out-of-stock components
    - Remove some of the 100nF caps that are in parallel with a larger value
    - Swap PTVS3V3 -> SD03
    - Swap the PMOS to HSU6119 and the NMOS to DOD130N06 for lower Rds(on)
    - Slightly increase the copper area around the FETs
    - Reduce the soft-start duration to 47 ms
    [BOM-Reflow Plate Controller.csv, BOM.csv, BOM.xlsx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]
2026-04-06 Thicken walls and add gussets to reduce warping risks
    [Assembly.f3z, Assembly.step, BOM.csv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]
2026-06-14 update zone fills (gerbers had a short circuit)
    [BOM-Reflow Plate Controller.csv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]
